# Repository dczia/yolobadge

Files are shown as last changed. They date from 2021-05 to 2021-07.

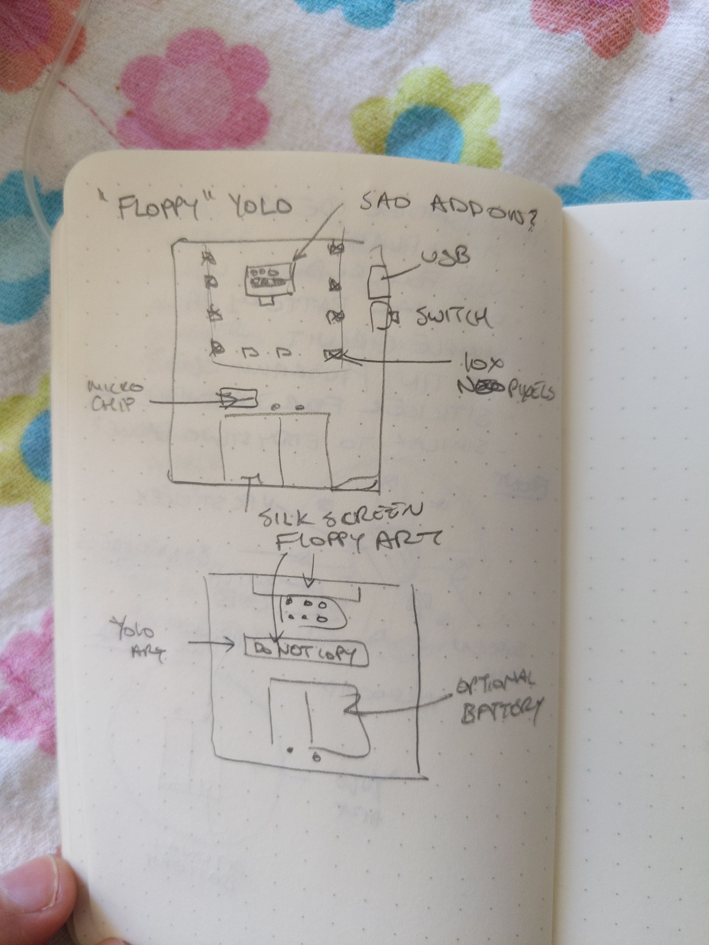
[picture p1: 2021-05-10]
Hardware/Images/image-75562de1-1c7d-4f85-8c4a-f190364c9026.jpg

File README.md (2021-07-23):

# yolobadge
Ziacon 2 / DefCon 29 #yolobadge 2021

A badge thought up, designed, and made in ~4 hours duing a live talk at ZiaCon 2, April 2021

Badge layout by @hamster  
Design input from @jediguybob @lithochasm and @DCZia  
Art from @LunaSylumDancer and Challenge from @Syntax  

```
             _       _               _            
 _   _  ___ | | ___ | |__   __ _  __| | __ _  ___ 
| | | |/ _ \| |/ _ \| '_ \ / _` |/ _` |/ _` |/ _ \
| |_| | (_) | | (_) | |_) | (_| | (_| | (_| |  __/
 \__, |\___/|_|\___/|_.__/ \__,_|\__,_|\__, |\___|
 |___/                                 |___/      

```

## Hardware

* ATMega 32U4 Microcontroller
* 10 Neopixel / WS2812B LED's
* Micro USB Power
* SAO Port
* Serial Breakout

## Software

Arduino Sketch using the FastLED libary to control the neopixels

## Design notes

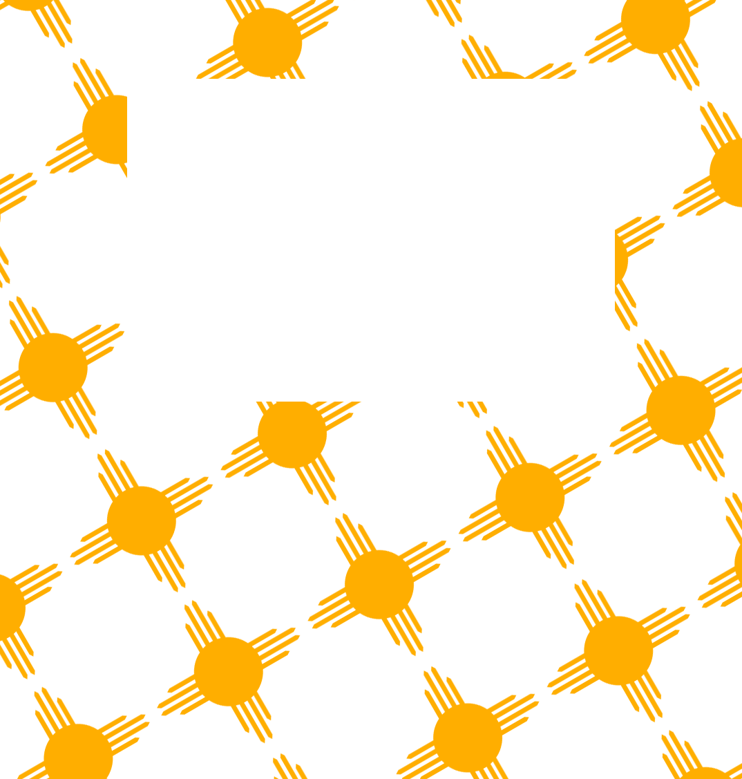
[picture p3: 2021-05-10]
Hardware/Images/zia label2.png

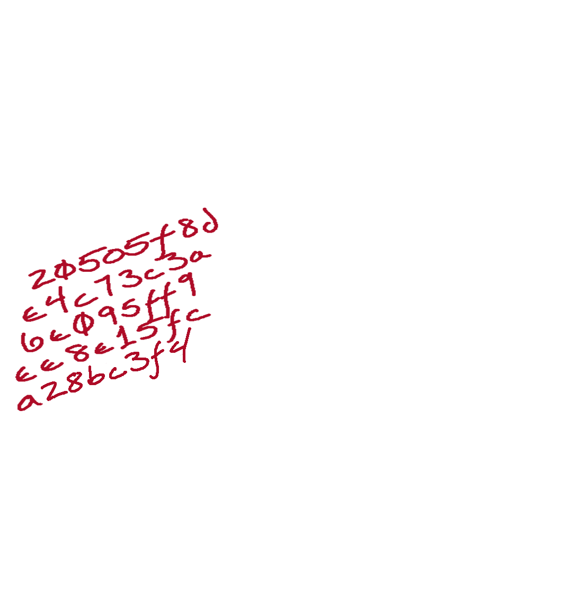
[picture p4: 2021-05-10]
Hardware/Images/Back Code.png

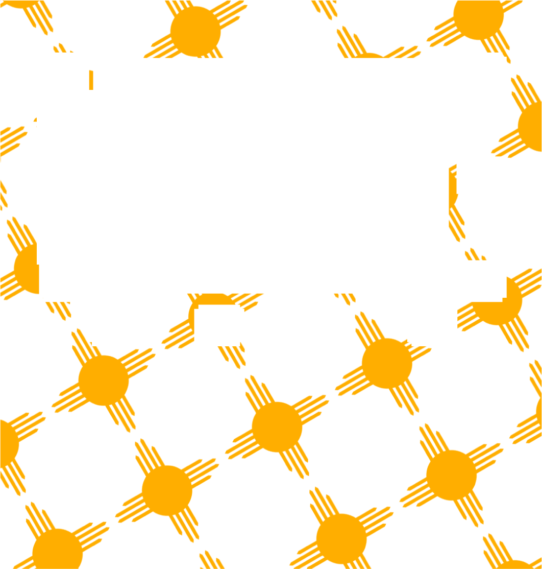
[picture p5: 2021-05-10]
Hardware/Images/FrontCopper.png

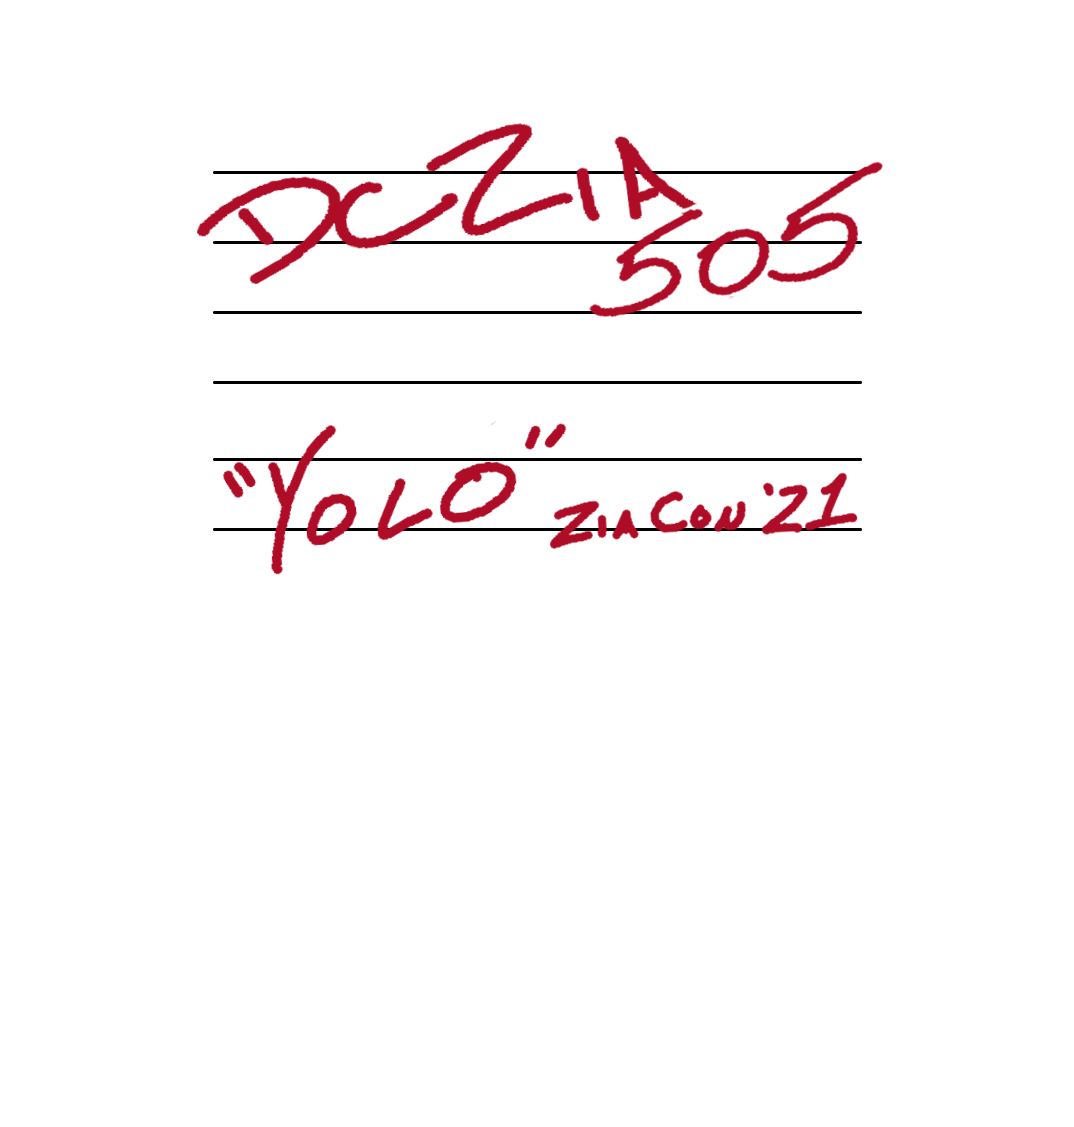
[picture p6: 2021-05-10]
Hardware/Images/Label Text.png

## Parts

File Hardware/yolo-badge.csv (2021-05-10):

Source: | C:\Users\hamster\Documents\Development\dczia\Ziacon2\yolo-badge.kicad_sch
Date: | 4/16/2021 23:26
Tool: | Eeschema (5.99.0-10336-g9846076676)
Generator: | C:\Program Files\KiCad\5.99\bin\scripting\plugins/bom_csv_grouped_by_value_with_fp.py
Component Count: | 32 |  |  |  |  |  |  |  |  |  |  | 50
Ref | Qnty | Value | Cmp name | Footprint | Description | Vendor | Part Number | Vendor Number | Price 100 | Qty | Total Price | Needed
C1, | 1 | 10uF | C | Capacitor_SMD:C_0603_1608Metric | Unpolarized capacitor |  |  | 587-6012-2-ND | 0.045 | 1 | 0.045 | 50
C2, C3, | 2 | 0.1uF | C | Capacitor_SMD:C_0603_1608Metric | Unpolarized capacitor |  |  | 478-06036C104KAT4ATR-ND | 0.0169 | 2 | 0.0338 | 100
C4, | 1 | 1uF | C | Capacitor_SMD:C_0603_1608Metric | Unpolarized capacitor |  |  | 1276-1036-2-ND | 0.0145 | 1 | 0.0145 | 50
C5, C6, | 2 | 12pF | C | Capacitor_SMD:C_0603_1608Metric | Unpolarized capacitor |  |  | 1292-1480-2-ND | 0.0124 | 2 | 0.0248 | 100
D1, D2, D3, D4, D5, D6, D7, D8, D9, D10, | 10 | WS2812B | WS2812B | LED_SMD:LED_WS2812B_PLCC4_5.0x5.0mm_P3.2mm | RGB LED with integrated controller |  |  |  | 0.25 | 10 | 2.5 | 500
D11, | 1 | Status | LED | LED_SMD:LED_0603_1608Metric | Light emitting diode |  |  | 160-1183-1-ND | 0.0611 | 1 | 0.0611 | 50
J1, | 1 | SPI | Conn_02x03_Odd_Even | Connector_PinHeader_2.54mm:PinHeader_2x03_P2.54mm_Vertical | Generic connector, double row, 02x03, odd/even pin numbering scheme (row 1 odd numbers, row 2 even numbers), script generated (kicad-library-utils/schlib/autogen/connector/) |  |  |  |  |  | 0 | 0
J2, | 1 | USB_B_Micro | USB_B_Micro-Connector_Specialized | Connector_USB:USB_Micro-B_Molex_47346-0001 |  |  |  | WM17141TR-ND | 0.6564 | 1 | 0.6564 | 50
JP3, | 1 | Bootloader | SolderJumper_2_Open | Jumper:SolderJumper-2_P1.3mm_Open_RoundedPad1.0x1.5mm | Solder Jumper, 2-pole, open |  |  |  |  |  | 0 | 0
R3, R4, | 2 | 22R | R | Resistor_SMD:R_0603_1608Metric | Resistor |  |  | RMCF0603JT22R0CT-ND | 0.0061 | 2 | 0.0122 | 100
R5, R7, | 2 | 10k | R | Resistor_SMD:R_0603_1608Metric | Resistor |  |  | RMCF0603JT10K0CT-ND | 0.0061 | 2 | 0.0122 | 100
R6, | 1 | 330R | R | Resistor_SMD:R_0603_1608Metric | Resistor |  |  | RMCF0603JT330RCT-ND | 0.0061 | 1 | 0.0061 | 50
RX1, | 1 | Test_Point | Test_Point-Connector_Specialized | TestPoint:TestPoint_Pad_2.0x2.0mm |  |  |  |  |  |  | 0 | 0
SW1, | 1 | SW_Push | SW_Push | lip_fp:Wurth_434331013822 | Push button switch, generic, two pins |  |  | 732-10144-2-ND | 0.4945 | 1 | 0.4945 | 50
TX1, | 1 | Test_Point | Test_Point-Connector_Specialized | TestPoint:TestPoint_Pad_2.0x2.0mm |  |  |  |  |  |  | 0 | 0
U1, | 1 | TPS73233DBVT | TPS73233DBVT | Package_TO_SOT_SMD:SOT-23-5 |  |  |  | 296-15812-2-ND | 1.1695 | 1 | 1.1695 | 50
U2, | 1 | ATmega32U4-AU | ATmega32U4-AU-MCU_Microchip_ATmega | Package_QFP:TQFP-44_10x10mm_P0.8mm |  | Digikey | ATMEGA32U4RC-AUR | ATMEGA32U4RC-AURTR-ND | 4.334 | 1 | 4.334 | 50
X1, | 1 | Badgelife_sao_connector_v169bis | Badgelife_sao_connector_v169bis | lip_fp:Badgelife-Shitty-v1.69bis |  |  |  |  |  |  | 0 | 0
Y1, | 1 | 16Mhz | Crystal | Crystal:Crystal_SMD_HC49-SD | Two pin crystal |  |  | 535-14879-2-ND | 0.2323 | 1 | 0.2323 | 50
Totals |  |  |  |  |  |  |  |  |  |  | 9.5964

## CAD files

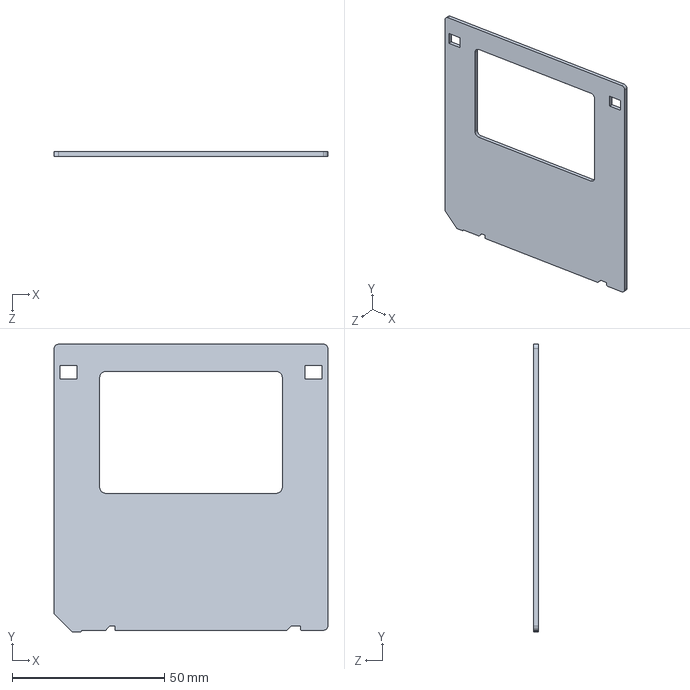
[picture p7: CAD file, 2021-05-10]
Hardware/Images/Top Board.SLDPRT
90.0 x 94.5 x 1.50 mm

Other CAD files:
Hardware/Images/Top Board.DXF

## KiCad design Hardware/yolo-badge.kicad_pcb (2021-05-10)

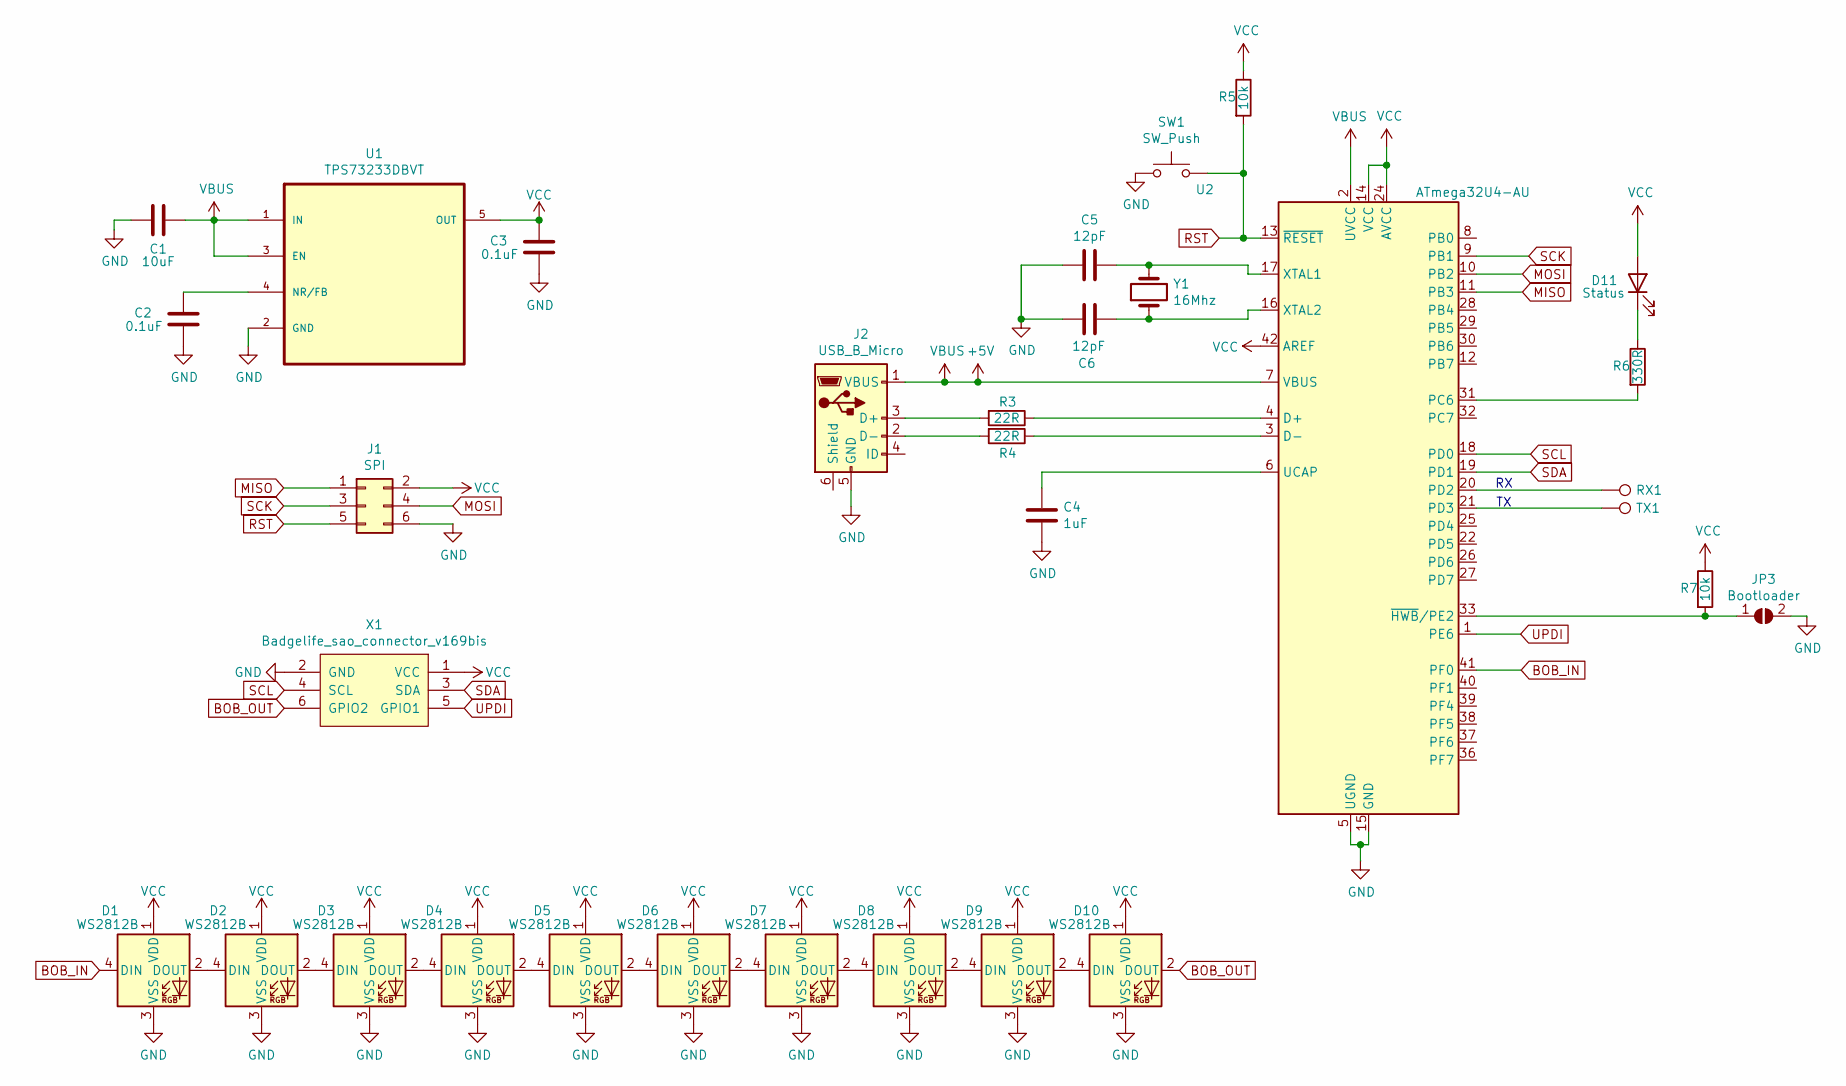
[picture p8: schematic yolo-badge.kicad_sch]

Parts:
C1: 10uF; C_0603_1608Metric
C2, C3: 0.1uF; C_0603_1608Metric
C4: 1uF; C_0603_1608Metric
C5, C6: 12pF; C_0603_1608Metric
D1, D2, D3, D4, D5, D6, D7, D8, D9, D10: WS2812B; LED_WS2812B_PLCC4_5.0x5.0mm_P3.2mm
D11: Status; LED_0603_1608Metric
J1: SPI; PinHeader_2x03_P2.54mm_Vertical
J2: USB_B_Micro; USB_Micro-B_Molex_47346-0001
JP3: Bootloader; SolderJumper-2_P1.3mm_Open_RoundedPad1.0x1.5mm
R3, R4: 22R; R_0603_1608Metric
R5, R7: 10k; R_0603_1608Metric
R6: 330R; R_0603_1608Metric
RX1: Test_Point; TestPoint_Pad_2.0x2.0mm
SW1: SW_Push; Wurth_434331013822
TX1: Test_Point; TestPoint_Pad_2.0x2.0mm
U1: TPS73233DBVT; SOT-23-5
U2: ATmega32U4-AU; TQFP-44_10x10mm_P0.8mm
X1: Badgelife_sao_connector_v169bis; Badgelife-Shitty-v1.69bis
Y1: 16Mhz; Crystal_SMD_HC49-SD

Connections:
+5V: C1.1, J2.1 (VBUS), U1.1 (IN), U1.3 (EN), U2.2 (UVCC), U2.7 (VBUS)
BOB_IN: D1.4 (DIN), U2.41 (PF0)
BOB_OUT: D10.2 (DOUT), X1.6 (GPIO2)
GND: C1.2, C2.1, C3.1, C4.2, C5.2, C6.2, D1.3 (VSS), D2.3 (VSS), D3.3 (VSS), D4.3 (VSS), D5.3 (VSS), D6.3 (VSS), D7.3 (VSS), D8.3 (VSS), D9.3 (VSS), D10.3 (VSS), J1.6, J2.5 (GND), JP3.2 (B), SW1.1, U1.2 (GND), U2.5 (UGND), U2.15 (GND), U2.23 (GND), U2.35 (GND), U2.43 (GND), X1.2 (GND)
MISO: J1.1, U2.11 (PB3)
MOSI: J1.4, U2.10 (PB2)
unnamed: C2.2, U1.4 (NR/FB)
unnamed: C4.1, U2.6 (UCAP)
unnamed: C5.1, U2.17 (XTAL1), Y1.2
unnamed: C6.1, U2.16 (XTAL2), Y1.1
unnamed: D1.2 (DOUT), D2.4 (DIN)
unnamed: D2.2 (DOUT), D3.4 (DIN)
unnamed: D3.2 (DOUT), D4.4 (DIN)
unnamed: D4.2 (DOUT), D5.4 (DIN)
unnamed: D5.2 (DOUT), D6.4 (DIN)
unnamed: D6.2 (DOUT), D7.4 (DIN)
unnamed: D7.2 (DOUT), D8.4 (DIN)
unnamed: D8.2 (DOUT), D9.4 (DIN)
unnamed: D9.2 (DOUT), D10.4 (DIN)
unnamed: D11.1 (K), R6.1
unnamed: J2.2 (D-), R4.2
unnamed: J2.3 (D+), R3.2
unnamed: JP3.1 (A), R7.2, U2.33 (~HWB~/PE2)
unnamed: R3.1, U2.4 (D+)
unnamed: R4.1, U2.3 (D-)
unnamed: R6.2, U2.31 (PC6)
unnamed: RX1.1, U2.20 (PD2)
unnamed: TX1.1, U2.21 (PD3)
RST: J1.5, R5.2, SW1.2, U2.13 (~RESET)
SCK: J1.3, U2.9 (PB1)
SCL: U2.18 (PD0), X1.4 (SCL)
SDA: U2.19 (PD1), X1.3 (SDA)
UPDI: U2.1 (PE6), X1.5 (GPIO1)
VCC: C3.2, D1.1 (VDD), D2.1 (VDD), D3.1 (VDD), D4.1 (VDD), D5.1 (VDD), D6.1 (VDD), D7.1 (VDD), D8.1 (VDD), D9.1 (VDD), D10.1 (VDD), D11.2 (A), J1.2, R5.1, R7.1, U1.5 (OUT), U2.14 (VCC), U2.24 (AVCC), U2.34 (VCC), U2.42 (AREF), U2.44 (AVCC), X1.1 (VCC)

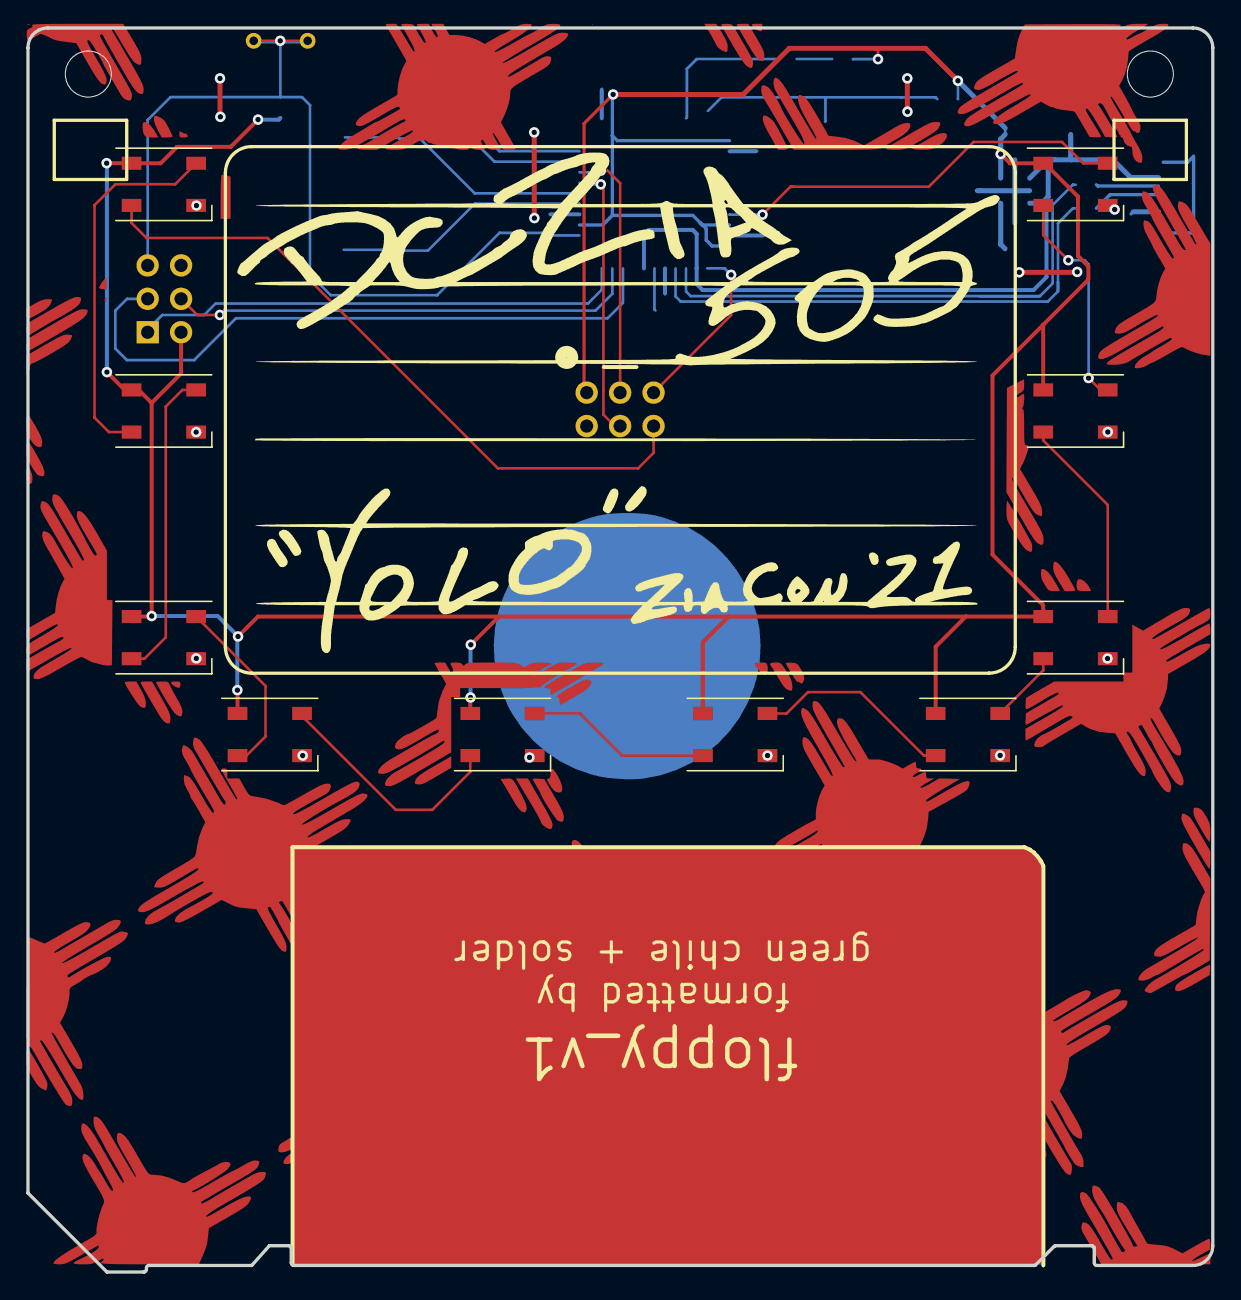
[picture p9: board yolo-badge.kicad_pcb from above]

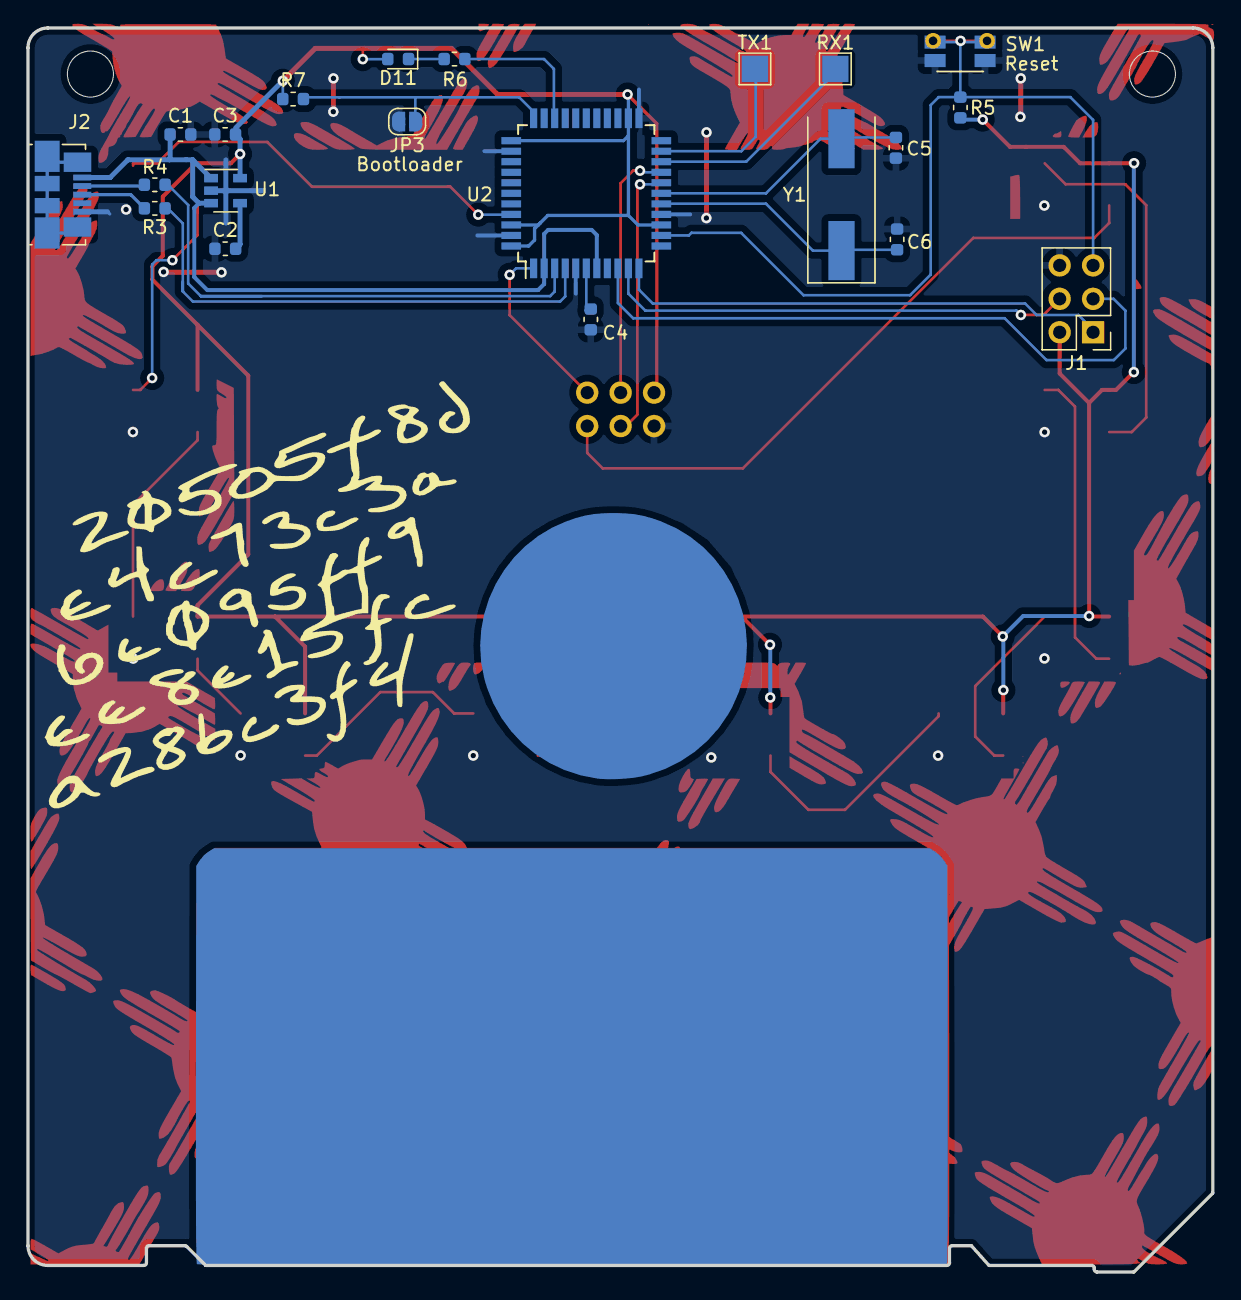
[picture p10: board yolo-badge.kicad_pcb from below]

Board: 2 copper layers, 90.0 x 94.5 mm, 32 parts (21 on the bottom side), 34 nets.

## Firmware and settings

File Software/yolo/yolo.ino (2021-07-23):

//  DCZia 2021 Badge Lighting Code
//  A mix of red, yellow, and oragnge to take you back to the desert
//  July 2021 @LithoChasm
//  For D
//

#define FASTLED_ALLOW_INTERRUPTS 0
#include <FastLED.h>

//FIXED GLOBAL VARS
#define DATA_PIN A5  //Define led data pin in
#define LED_TYPE WS2811  //define type of led
#define COLOR_ORDER GRB
#define NUM_LEDS 10  //num of leds in strip
#define FRAMES_PER_SECOND  120
#define BRIGHTNESS          15

CRGB leds[NUM_LEDS];

int FastLED_fade_counter = 0;
bool startup_done = false;


void setup() {
  // put your setup code here, to run once:
  delay(2000); //for safe startup
  Serial.begin(9600); // open the serial port at 9600 bps:
  FastLED.addLeds<LED_TYPE,DATA_PIN,COLOR_ORDER>(leds, NUM_LEDS).setCorrection(TypicalLEDStrip);
  FastLED.setBrightness(BRIGHTNESS);
  FastLED.clear();  // clear old data if exsists

}

// List of patterns to cycle through.  Each is defined as a separate function below.
typedef void (*SimplePatternList[])();
SimplePatternList gPatterns = { main_viz, viz2, viz3 };

uint8_t gCurrentPatternNumber = 0; // Index number of which pattern is current
uint8_t gHue = 0;

void loop() {

  EVERY_N_MILLISECONDS( 20 ) { gHue++; } // slowly cycle the "base color" through the rainbow
  EVERY_N_SECONDS( 10 ) { nextPattern(); } // change patterns periodically
  
  if (startup_done == false) {
    startup_animation();
  }
  else {
// Call the current pattern function once, updating the 'leds' array
  gPatterns[gCurrentPatternNumber]();

  }

  FastLED.show();
    // insert a delay to keep the framerate modest
  FastLED.delay(1000/FRAMES_PER_SECOND); 

}

#define ARRAY_SIZE(A) (sizeof(A) / sizeof((A)[0]))

void nextPattern()
{
  // add one to the current pattern number, and wrap around at the end
  gCurrentPatternNumber = (gCurrentPatternNumber + 1) % ARRAY_SIZE( gPatterns);
}

void startup_animation() {
Serial.println("In Startup");

    // Fade up all LEDs to Red from off / black
    for ( int i = 0; i < NUM_LEDS; i++ )
          {
            leds[i] = CRGB::Red; // Fade up to red
            leds[i].maximizeBrightness(FastLED_fade_counter);  // 'FastLED_fade_counter' How high we want to fade up to 255 = maximum.
          }

          FastLED_fade_counter ++ ;   // Increment
          Serial.println(FastLED_fade_counter);
          if (FastLED_fade_counter == 255) {
            startup_done = true;
            FastLED.clear();  // clear old data if exsists
          }
          delay(5);
  }

void main_viz() {
  
  //Serial.println("GHue = " + gHue);
  //fill_rainbow( leds, NUM_LEDS, gHue, 3);
  fill_rainbow( leds, NUM_LEDS, HUE_RED, 5);
  fill_rainbow( leds, NUM_LEDS, HUE_ORANGE, 3);
  fill_rainbow( leds, NUM_LEDS, HUE_RED, 5);

}

void viz2() {
  fadeToBlackBy( leds, NUM_LEDS, 20);
  byte dothue = 0;
  for( int i = 0; i < 8; i++) {
    leds[beatsin16( i+7, 0, NUM_LEDS-1 )] |= CHSV(dothue, 200, 255);
    dothue += 32;
  }
}


void viz3() {

}

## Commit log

2021-05-10 Initial commit of the as-built rev 0 board
    [Top Board.DXF, Top Board.SLDPRT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]
2021-07-22 Cleaned up swap file. (╯°□°)╯︵ ┻━┻
